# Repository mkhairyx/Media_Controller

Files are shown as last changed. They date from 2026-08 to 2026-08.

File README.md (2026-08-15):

# Gesture Based Media controller

## What is it
It's a device that controls your TV using IR signals to mimic your TV's remote control. It detects a gesture and then sends the signal that was coded for that gesture.

## The reason I made it
I made it so I can control different media without having to touch anything with my dirty hands while eating.

## Main modules used
- MCU: An ESP32
- Gesture Sensor: PAJ7620
- Display: OLED 0.96" SSD1306 Display

## Pins and their usages
- GPIO4: IR LED
- GPIO15: IR receiver (TL1838)
- GPIO21: SDA (for both the Gesture Sensor and the display)
- GPIO22: SCL (for both the Gesture Sensor and the display)
- GPIO18: delete button (Internally pulled high)

## How to recreate
You can either make the PCB with is [here](./source/pcbway_production/) or connect everything on a breadboard (while using [this](./README.md#pins-and-their-usages) as a reference) then you can flash the software provided [here](./Source/Arduino/Media_Controller_IRTXnRX) to your ESP32.

## Gestures and their functions
- Move Up / Move Down:<br>
Up Button / Down Button
- Move Left / Move Right:<br>
Left Button / Right Button
- Move Forward:<br>
OK button (for TV)
- Circle Clockwise (CW) / Circle Counter-Clockwise (CCW):<br>
Volume Up Button / Volume Down Button
- Wave (shake):<br>
switch between different TV/PC (Inoperative for now, PC functions will be available in V2)

## Demo Video
A demo vid can be watched here:<br>
https://youtu.be/PJmMg9s-Np0
https://cdn.hackclub.com/01a003da-1a12-7c9f-beef-b3fb1ff95faa/Media%20Controller%20Demo-2.mp4

## Notes
- Please note that AI was used to help with **some** parts of the code and not all of it.
- This is the first version of this project and it doesn't have all of the functions. V2 will have battery percentage measurement, better UI, and will be compatible with both TV and PC with the ability to switch between them.

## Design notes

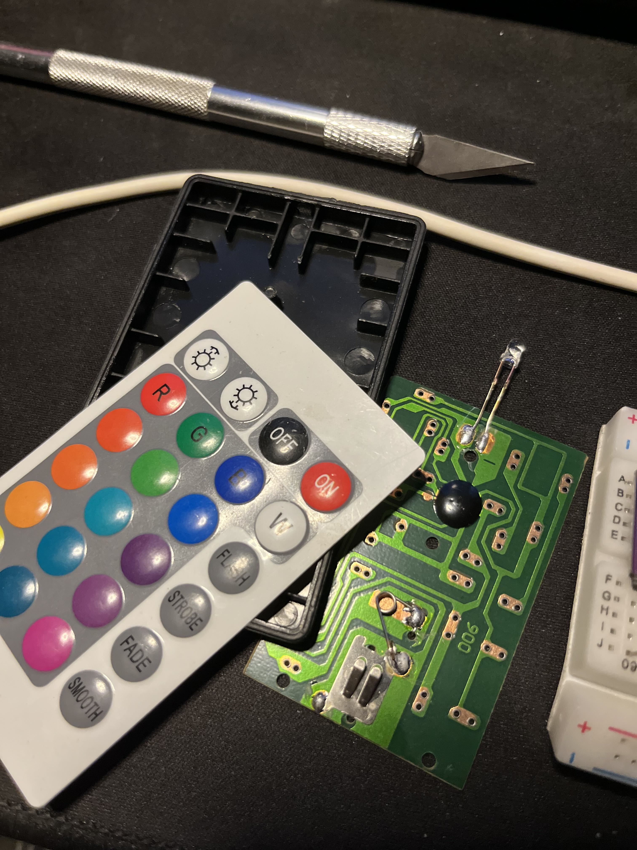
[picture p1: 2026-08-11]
Media/Camera/IR_Remote.jpg

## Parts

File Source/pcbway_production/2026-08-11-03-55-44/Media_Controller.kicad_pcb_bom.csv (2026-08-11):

Designator | Quantity | Value | Footprint | Package | MPN | DNP | Mount_Type | Description | KiLib_Generator | Sim.Pins | MF | Price | Check_prices | SnapEDA_Link | MP | Purchase-URL | Availability | MANUFACTURER | OC_FARNELL | SUPPLIER | OC_NEWARK
C1, C2, C3, C6 | 4 | 4.7uF | C_1206_3216Metric_Pad1.33x1.80mm_HandSolder |  |  |  | smt | Unpolarized capacitor | SMD_2terminal_chip_molded
C4 | 1 | 2.2uF | C_0805_2012Metric_Pad1.18x1.45mm_HandSolder |  |  |  | smt | Unpolarized capacitor | SMD_2terminal_chip_molded
C5, C7 | 2 | 100nF | C_1206_3216Metric_Pad1.33x1.80mm_HandSolder |  |  |  | smt | Unpolarized capacitor | SMD_2terminal_chip_molded
CHG1, PWR1 | 2 | SZYY0603Y | LED_0805_2012Metric_Pad1.15x1.40mm_HandSolder |  |  |  | smt | Light emitting diode | SMD_2terminal_chip_molded | 1=K 2=A
D1 | 1 | MBR120LSF | D_SMA_Handsoldering |  |  |  | smt | Schottky diode
D2 | 1 | IR | LED_D5.0mm |  |  |  | tht | Light emitting diode | LED/THT | 1=K 2=A
J1 | 1 | USB_C_Receptacle_USB2.0_16P | USB_C_Receptacle_GCT_USB4105-xx-A_16P_TopMnt_Horizontal |  |  |  | smt | USB 2.0-only 16P Type-C Receptacle connector
J2 | 1 | S2B-PH-SM4-TB | JST_EH_B2B-EH-A_1x02_P2.50mm_Vertical | None |  |  | tht | Connector Header Surface Mount, Right Angle 2 position 0.079 (2.00mm) | connector/JST |  | JST Sales | None | https://www.snapeda.com/parts/S2B-PH-SM4-TB/JST/view-part/?ref=eda | https://www.snapeda.com/parts/S2B-PH-SM4-TB/JST/view-part/?ref=snap | S2B-PH-SM4-TB | https://www.snapeda.com/api/url_track_click_mouser/?unipart_id=225866&manufacturer=JST Sales&part_name=S2B-PH-SM4-TB&search_term=s2b-ph-sm4-tb | In Stock | JST
J3 | 1 | polarity_ctrl | PinHeader_2x03_P2.54mm_Vertical |  |  |  | tht | Generic connector, double row, 02x03, odd/even pin numbering scheme (row 1 odd numbers, row 2 even numbers), script generated (kicad-library-utils/schlib/autogen/connector/) | connector/pin_header_socket
J4 | 1 | OLED | PinSocket_1x04_P2.54mm_Vertical |  |  |  | tht | Generic connector, single row, 01x04, script generated (kicad-library-utils/schlib/autogen/connector/) | connector/pin_header_socket
J5 | 1 | Gesture | PinSocket_1x05_P2.54mm_Vertical |  |  |  | tht | Generic connector, single row, 01x05, script generated | connector/pin_header_socket
Q3 | 1 | AO3401 | SOT-23 |  |  |  | smt | -0.18A Id, -60V Vds, P-Channel MOSFET, SOT-23 | package/gullwing
R1, R2 | 2 | 5.1k | R_Axial_DIN0207_L6.3mm_D2.5mm_P7.62mm_Horizontal |  |  |  | tht | Resistor | resistor/THT
R10 | 1 | 10k | R_0805_2012Metric_Pad1.20x1.40mm_HandSolder |  |  |  | smt | Resistor | SMD_2terminal_chip_molded
R11, R4, R5 | 3 | 2K | R_0805_2012Metric_Pad1.20x1.40mm_HandSolder |  |  |  | smt | Resistor | SMD_2terminal_chip_molded
R3, R6 | 2 | 10K | R_0805_2012Metric_Pad1.20x1.40mm_HandSolder |  |  |  | smt | Resistor | SMD_2terminal_chip_molded
R7 | 1 | 100 | R_0805_2012Metric_Pad1.20x1.40mm_HandSolder |  |  |  | smt | Resistor | SMD_2terminal_chip_molded
R8, R9 | 2 | 100K | R_0805_2012Metric_Pad1.20x1.40mm_HandSolder |  |  |  | smt | Resistor | SMD_2terminal_chip_molded
SW1 | 1 | Del | SW_PUSH_6mm_H13mm |  |  |  | tht | Push button switch, generic, two pins
SW3 | 1 | K3-1296S-E1_C128955 | SW_Slide_SPDT_Angled_CK_OS102011MA1Q |  |  |  | tht | Switch slide, single pole double throw
U1 | 1 | TSOP1838 | TSOP1838 | None |  |  | tht | IR Remote Receiver 38KHz 35m 3-Pin |  |  | Vishay | None | https://www.snapeda.com/parts/TSOP1838/Vishay/view-part/?ref=eda | https://www.snapeda.com/parts/TSOP1838/Vishay/view-part/?ref=snap | TSOP1838 | https://www.snapeda.com/api/url_track_click_mouser/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 | In Stock
U2 | 1 | MCP73831T-2ACI_OT | SOT-23-5_HandSoldering | SOT-5 | MCP73831T-2ACI/OT |  | smt | TINY INTEGRATED LI-ION/LI-POLY CHARGE MGNT CONTROLLER, 4.2V VREG | Microchip Technology Inc. MCP73831T-2ACI/OT |  |  | Microchip | None | https://www.snapeda.com/parts/MCP73831T-2ACI/OT/Microchip+Technology/view-part/?ref=eda | https://www.snapeda.com/parts/MCP73831T-2ACI/OT/Microchip+Technology/view-part/?ref=snap | MCP73831T-2ACI/OT | https://www.snapeda.com/api/url_track_click_mouser/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 | In Stock |  | 1332158 | Microchip | 56K7045
U4 | 1 | MIC5219-3.3YM5 | SOT-23-5_HandSoldering |  |  |  | smt | 500mA low dropout linear regulator, fixed 3.3V output, SOT-23-5
U6 | 1 | ~ | ESP32 DevKit |  |  |  | smt

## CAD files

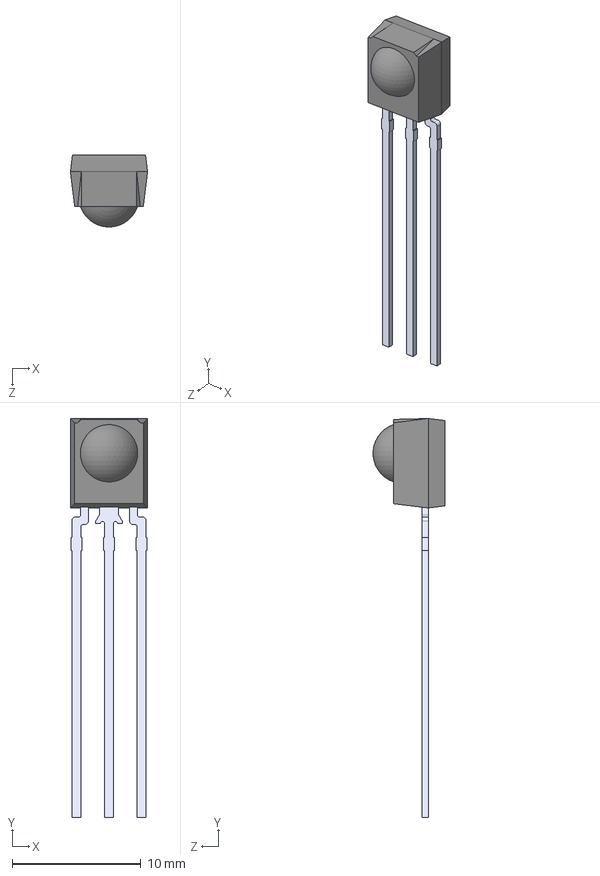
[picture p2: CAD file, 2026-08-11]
Source/KiCad/add-ons/TSOP1838/3D model/TSOP1838--3DModel-STEP-510211.STEP
6.00 x 31.0 x 5.59 mm

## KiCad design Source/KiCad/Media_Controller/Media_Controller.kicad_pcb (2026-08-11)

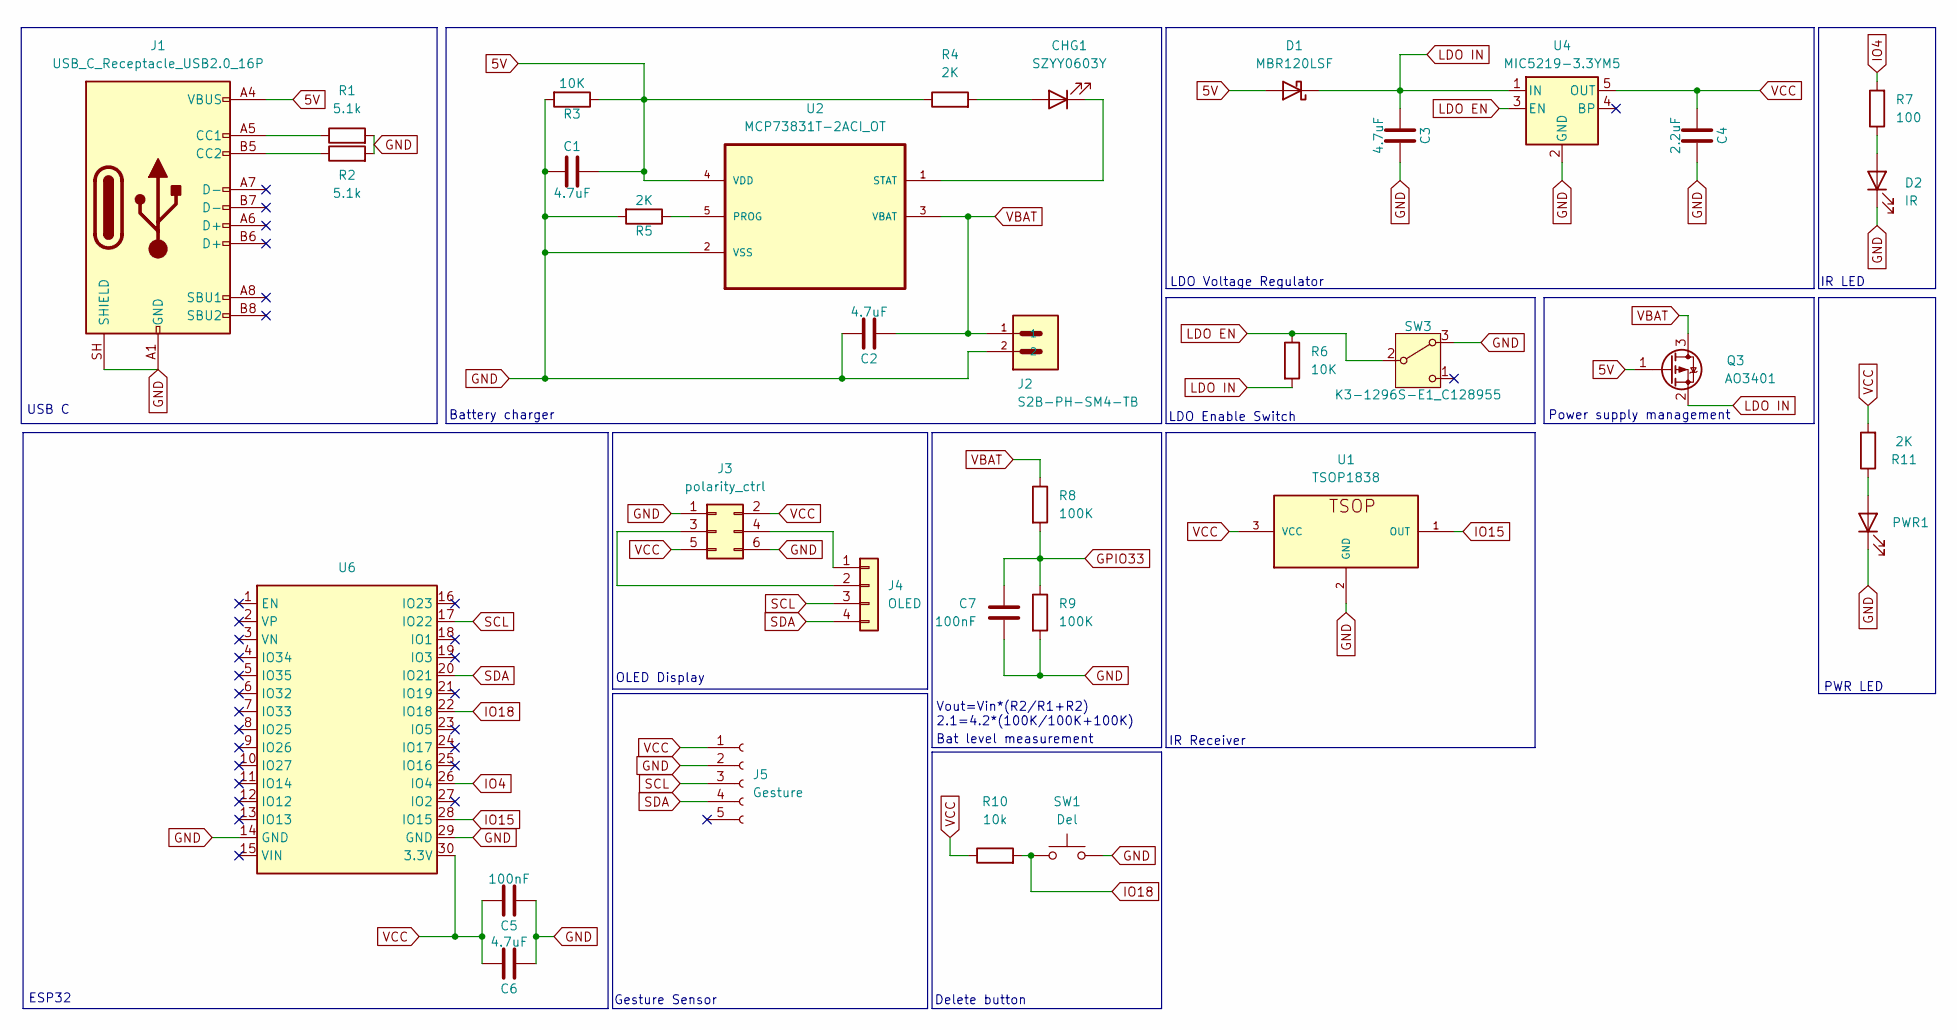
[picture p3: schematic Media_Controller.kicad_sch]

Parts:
C1, C2, C3, C6: 4.7uF; C_1206_3216Metric_Pad1.33x1.80mm_HandSolder
C4: 2.2uF; C_0805_2012Metric_Pad1.18x1.45mm_HandSolder
C5, C7: 100nF; C_1206_3216Metric_Pad1.33x1.80mm_HandSolder
CHG1: SZYY0603Y; LED_0805_2012Metric_Pad1.15x1.40mm_HandSolder
D1: MBR120LSF; D_SMA_Handsoldering
D2: IR; LED_D5.0mm
J1: USB_C_Receptacle_USB2.0_16P; USB_C_Receptacle_GCT_USB4105-xx-A_16P_TopMnt_Horizontal
J2: S2B-PH-SM4-TB; JST_EH_B2B-EH-A_1x02_P2.50mm_Vertical
J3: polarity_ctrl; PinHeader_2x03_P2.54mm_Vertical
J4: OLED; PinSocket_1x04_P2.54mm_Vertical
J5: Gesture; PinSocket_1x05_P2.54mm_Vertical
PWR1: SZYY0603Y; LED_0805_2012Metric_Pad1.15x1.40mm_HandSolder
Q3: AO3401; SOT-23
R1, R2: 5.1k; R_Axial_DIN0207_L6.3mm_D2.5mm_P7.62mm_Horizontal
R3, R6: 10K; R_0805_2012Metric_Pad1.20x1.40mm_HandSolder
R4, R5, R11: 2K; R_0805_2012Metric_Pad1.20x1.40mm_HandSolder
R7: 100; R_0805_2012Metric_Pad1.20x1.40mm_HandSolder
R8, R9: 100K; R_0805_2012Metric_Pad1.20x1.40mm_HandSolder
R10: 10k; R_0805_2012Metric_Pad1.20x1.40mm_HandSolder
SW1: Del; SW_PUSH_6mm_H13mm
SW3: K3-1296S-E1_C128955; SW_Slide_SPDT_Angled_CK_OS102011MA1Q
U1: TSOP1838
U2: MCP73831T-2ACI_OT; SOT-23-5_HandSoldering; MPN MCP73831T-2ACI/OT
U4: MIC5219-3.3YM5; SOT-23-5_HandSoldering
U6: ESP32 DevKit

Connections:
5V: C1.2, D1.2 (A), J1.A4 (VBUS), J1.A9 (VBUS), J1.B4 (VBUS), J1.B9 (VBUS), Q3.1 (G), R3.1, R4.1, U2.4 (VDD)
GND: C1.1, C2.2, C3.2, C4.2, C5.1, C6.1, C7.2, D2.1 (K), J1.A1 (GND), J1.A12 (GND), J1.B1 (GND), J1.B12 (GND), J1.SH (SHIELD), J2.2, J3.1, J3.6, J5.2, PWR1.1 (K), R1.2, R2.2, R3.2, R5.2, R9.2, SW1.2, SW3.3 (A), U1.2 (GND), U2.2 (VSS), U4.2 (GND), U6.14 (GND), U6.29 (GND)
GPIO33: C7.1, R8.2, R9.1
IO4: R7.2, U6.26 (IO4)
IO15: U1.1 (OUT), U6.28 (IO15)
IO18: R10.2, SW1.1, U6.22 (IO18)
LDO EN: R6.1, SW3.2 (B), U4.3 (EN)
LDO IN: C3.1, D1.1 (K), Q3.2 (S), R6.2, U4.1 (IN)
unnamed: CHG1.2 (A), R4.2
unnamed: CHG1.1 (K), U2.1 (STAT)
unnamed: D2.2 (A), R7.1
unnamed: J1.A5 (CC1), R1.1
unnamed: J1.B5 (CC2), R2.1
unnamed: J3.3, J4.2
unnamed: J3.4, J4.1
unnamed: PWR1.2 (A), R11.1
unnamed: R5.1, U2.5 (PROG)
SCL: J4.3, J5.3, U6.17 (IO22)
SDA: J4.4, J5.4, U6.20 (IO21)
VBAT: C2.1, J2.1, Q3.3 (D), R8.1, U2.3 (VBAT)
VCC: C4.1, C5.2, C6.2, J3.2, J3.5, J5.1, R10.1, R11.2, U1.3 (VCC), U4.5 (OUT), U6.30 (3.3V)

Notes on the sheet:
PWR LED
OLED Display
Delete button
LDO Enable Switch
Gesture Sensor
Power supply management
ESP32
IR Receiver
IR LED
Battery charger
Bat level measurement
USB C
Vout=Vin*(R2/R1+R2) 2.1=4.2*(100K/100K+100K)
LDO Voltage Regulator

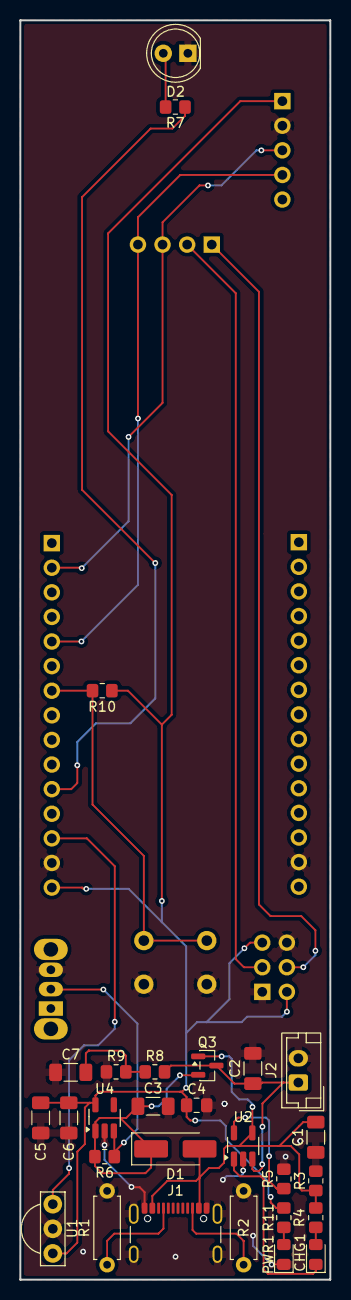
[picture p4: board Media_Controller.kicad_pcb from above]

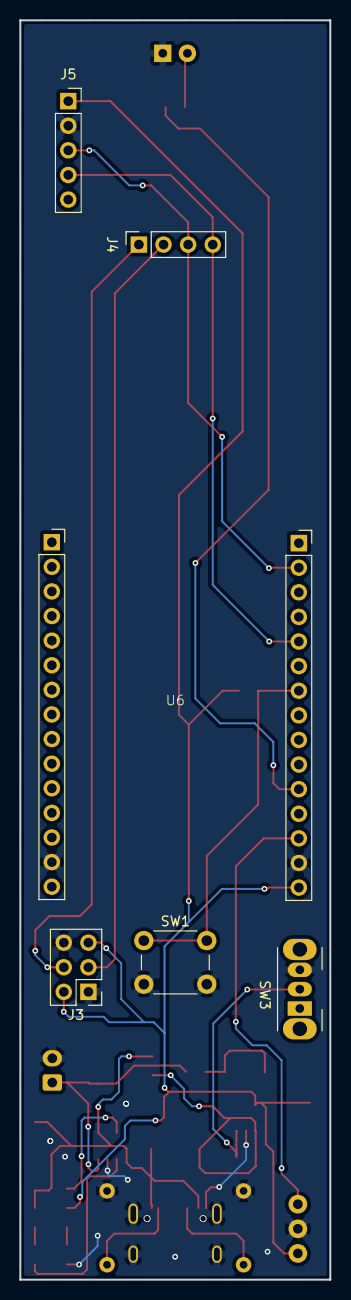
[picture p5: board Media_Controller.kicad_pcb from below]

Board: 2 copper layers, 32.0 x 130.0 mm, 34 parts (6 on the bottom side), 21 nets.

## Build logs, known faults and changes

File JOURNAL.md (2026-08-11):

---
title: "Gesture Based Media Controller"
author: "Mohamed Khairy"
description: "Touchless Gesture Based Media Controller that works with PC/TV"
created at: "2026-07-12"
---
### Total time spent: -- Hours

## Entry 1 - Getting started! - July 12th - 1.15 Hours

### Sketching out the design

At first I thought about making the device so it has a gesture sensor for media controls, and buttons for switching profiles (TV, PC, etc.).

Here's how I intended the design to look like:
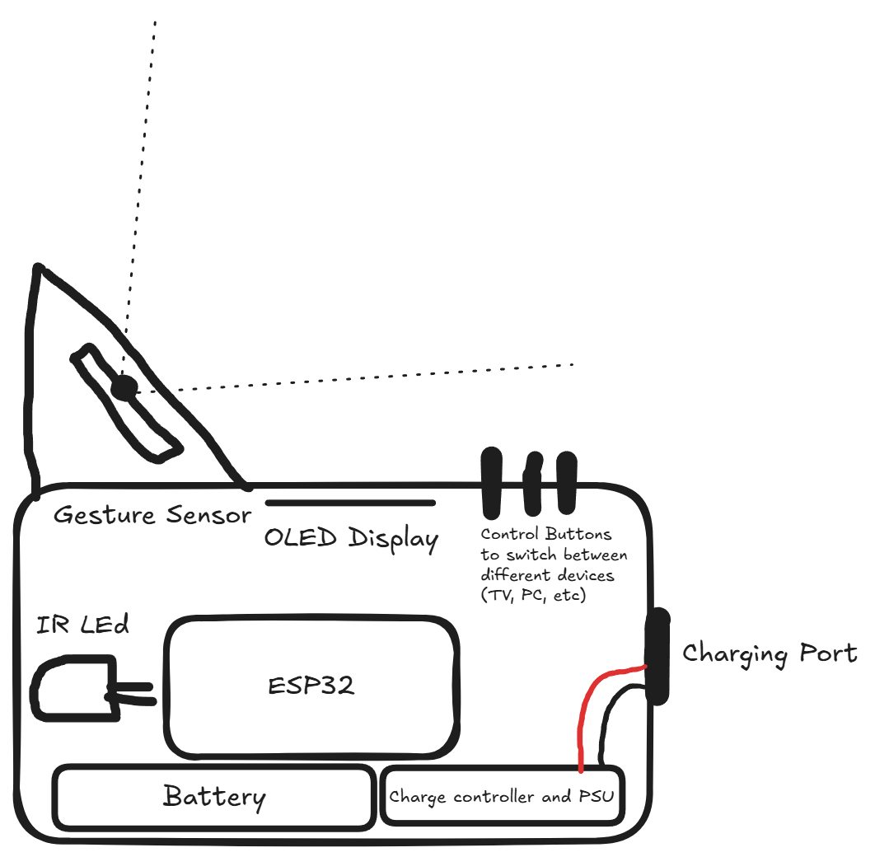
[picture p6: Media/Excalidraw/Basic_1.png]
Basic_1


But then I thought there's no need for the buttons, as I can use one of the gestures supported by the sensor to switch between TV/PC (using the Move Forward / Move Backward gestures). So I removed them and changed the design to not have them:
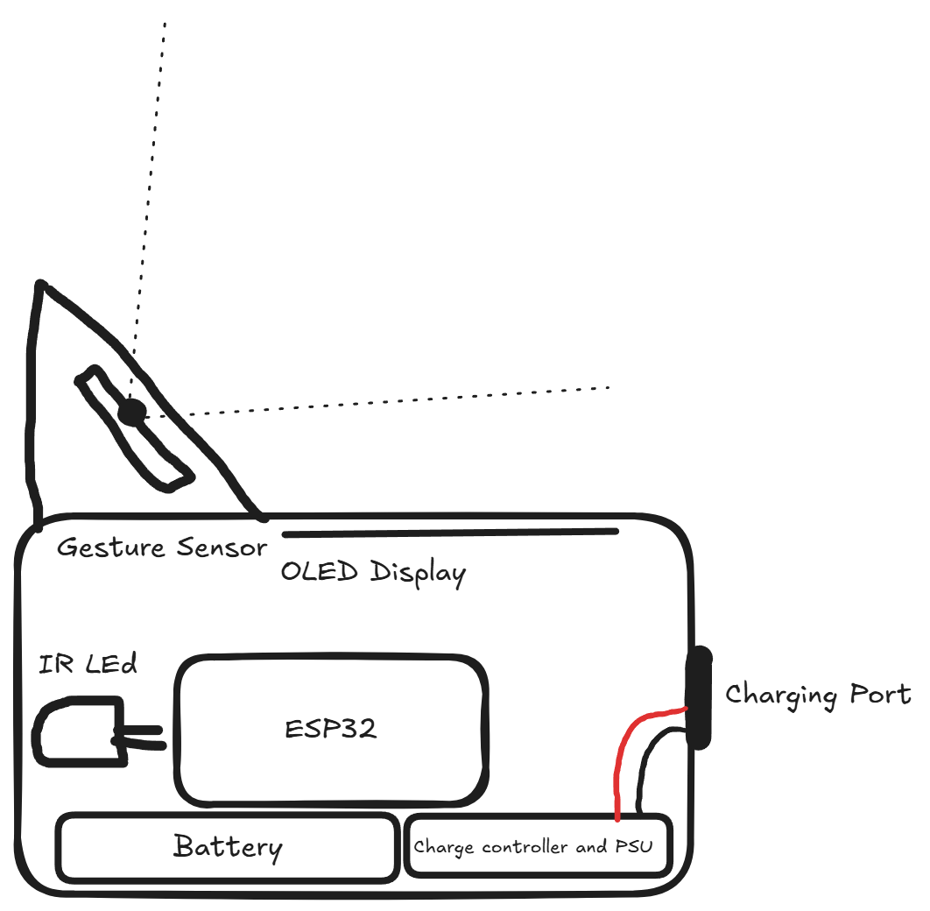
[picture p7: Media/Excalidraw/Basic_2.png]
Basic_2


Lapse recordings: <br>
[Media controller: Basic layout
](https://lapse.hackclub.com/timelapse/S1fzYW-wXMCX)<br>
[Finishing the 1st journal for media controller](https://lapse.hackclub.com/timelapse/r31FpIBMZaq-)<br>
***

## Entry 2 - Making a demo - August 8th - 2.05 Hours

### Putting the stuff on a breadboard

I Soldered some header pins to the gesture sensor and then I put everything on a breadboard.
I have the ESP32, the OLED display (which it's driver is a SSD1306) and the gesture sensor (A PAJ7620).<br>
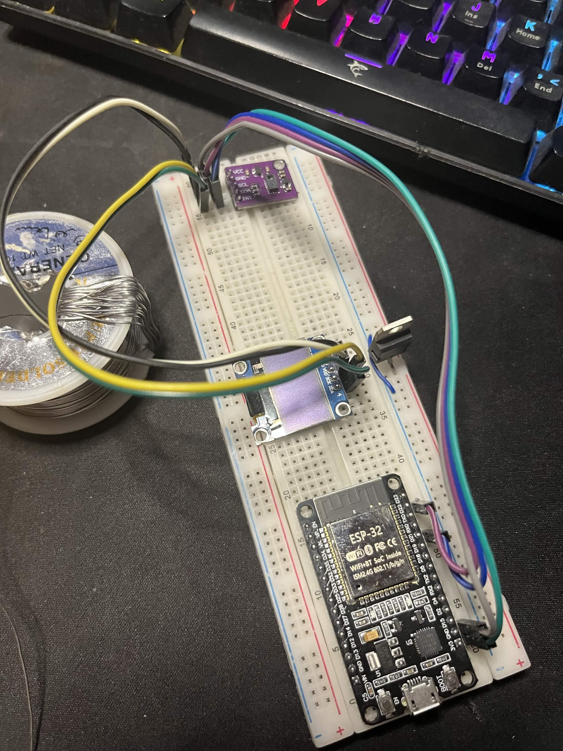
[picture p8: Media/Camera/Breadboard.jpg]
Breadboard
<br>

### Making a demo code

I ran a demo code for the sensor and everything worked great except one thing, the forward/backward gestures.<br>

After doing the forward gesture, you will have to pull your hand away, which triggers a false backward gesture.
Same thing with the backward gesture, you need to put your hand in front of the sensor then move away. Putting your hand in front of the sensor triggers a wrong gesture (wether be it a left, right, up, or down gesture).<br>

So I decided to disable the backward gesture and add a delay after the forward sensor so the user has time to pull away.<br>

After that, I ran some graphic tests from the U8g2 library to test the display. It worked great and I modified my code so it shows what gesture was recognized.

Then I added a rep counter so it shows how many times did you repeat the gesture.<br>

But after adding that, the ESP32 stopped recognizing gestures. So I decided to upload the original test code without my modifications to see if it will work or not, and it did work! <br>

Then I realized that the problem was with the rep counting function. Instead of changing the variable storing the last gesture, I was changing the variable storing the current gesture, which made it look like there is no gestures. I fixed it and it worked great!
<br>

Then I researched how to chain clockwise/counter-clockwise gestures. I gotta admit I used AI on this one, but I didn't fully rely on it. <br>
I spent some time fine tunning and testing the angles and gestures debouncing and it's working great!<br>

** a pic of the project with the screen displaying stuff **
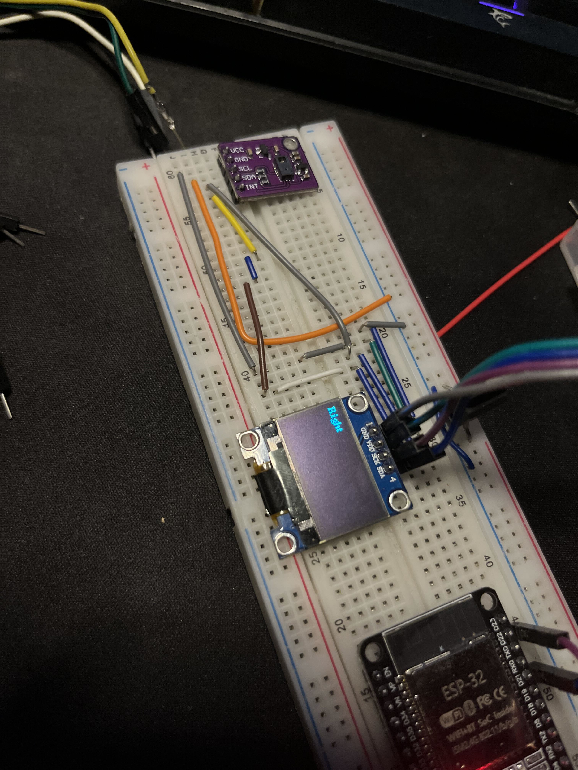
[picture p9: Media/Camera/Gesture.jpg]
Gesture


### What I'm doing next

Here's what I will be doing next:<br>
- get the ir sender and receiver ready
- make a test code that reads ir signals
- make a test code that sends hard coded ir signals
- make a test code that sends user coded ir signal (using an ir receiver)
- Make a code that pairs to a pc and controls media over bluetooth
- merge both functions together and let the user decided which function to use
- Make cool graphics for the display

<br>

Lapse recordings: <br>
[Making a code to interpret gestures](https://lapse.hackclub.com/timelapse/9EifI0f1eVn_)
 ***

## Entry 3 - Messing around with IR - August 8th - 0.9 Hours

### Getting the Breadboard ready

I put the IR receiver (TL1838 VS1838B) on the breadboard so I can mess around with it and figure out how the IR protocol works.

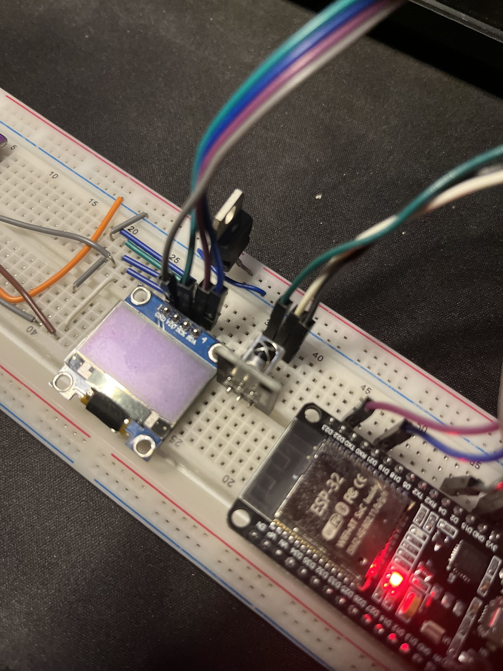
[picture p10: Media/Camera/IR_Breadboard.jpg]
IR_Breadboard


### Figuring out which protocol my TV uses

Using an oscilloscope, I discovered that my remote operates on NEC protocol which has a 1T of 562 µs.

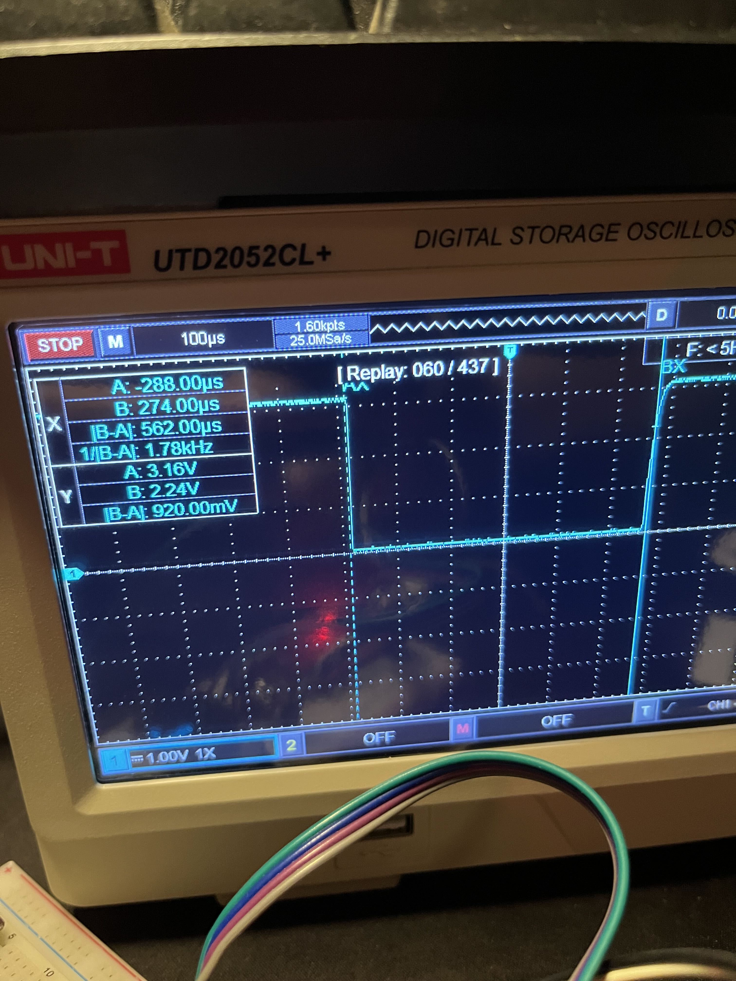
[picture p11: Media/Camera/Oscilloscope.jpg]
Oscilloscope


So I had claude make a code that reads IR signals and shows them to me on the serial monitor.<br>

It was getting late so  I decided that's enough for today.

### What I'm doing next

Here's what I will be doing next:<br>
- make a test code that sends hard coded ir signals
- make a test code that sends user coded ir signal (using an ir receiver)
- Make a code that pairs to a pc and controls media over bluetooth
- merge both functions together and let the user decided which function to use
- Make cool graphics for the display

<br>

Lapse recordings: <br>
[Testing IR receiver](https://lapse.hackclub.com/timelapse/zANNEGai21DX)
***

## Entry 4 - Sending signals with IR - August 9th - 1.3 Hours

### Getting an IR sender LED

I didn't have an IR LED so I decided to salvage one from my RGB LEDs controller.

** image of controller stripped apart **

### Making a test code for the IR led

I made a code for the IR LED to send hardcoded signals when some gestures are recognized but it didn't work. I accidentally burned the IR LED so I had to get another remote so I can salvage another LED and not burn it this time.

The code worked and the TV recognized the signals!

I spent some time trying to figure out how to store the IR data into the ESP32 non volatile storage. But I think I have done Enough for today.
<br>

Lapse recordings: <br>
[Getting the IR working](https://lapse.hackclub.com/timelapse/jJdBno_JCZZk)
***

## Entry 5 - Storing IR signals dynamically - August 10th - 2.2 Hours

Nothing much to say.
I made a code that utilizes the ESP32 NVS and stores the signals.<br>
I have also added a button that deletes the stored data (in case the user is having a new TV or anything similar).<br>

I was planning to make this device work with both TV and PC and I was going to make a better UI for it but I won't be able to do so as I'm extremely short on time. I'm satisfied with how it works for the moment.<br>

What's left is to make the schematic and the PCB for the device, then the enclosure.
<br>

Lapse recordings: <br>
[Storing IR signals dynamically](https://lapse.hackclub.com/timelapse/v13pgNrjCIoe)
***

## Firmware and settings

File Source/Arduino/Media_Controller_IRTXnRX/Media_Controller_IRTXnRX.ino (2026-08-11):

/////////////////////////////////////////////////////////////////////////////////
// This code does not have analog battery measurement for the moment.          //
// Analog battery mesurement will be added to the next version of this code.   //
//https://github.com/mkhairyx                                                  //
/////////////////////////////////////////////////////////////////////////////////

#include <Arduino.h>


// ESP32 NVS Headers
#include <Preferences.h>
Preferences TV;

// Display Library Headers
#include <U8g2lib.h>
U8G2_SSD1306_128X64_NONAME_F_HW_I2C u8g2(U8G2_R0, /* reset=*/ U8X8_PIN_NONE);
#ifdef U8X8_HAVE_HW_SPI
#include <SPI.h>
#endif
#ifdef U8X8_HAVE_HW_I2C
#include <Wire.h>
#endif

void u8g2_prepare(void) {
  u8g2.setFont(u8g2_font_6x10_tf);
  u8g2.setFontRefHeightExtendedText();
  u8g2.setDrawColor(1);
  u8g2.setFontPosTop();
  u8g2.setFontDirection(0);
}

bool del = 0;
volatile bool del_touch = 0;
#define delete_pin 18
void delete_function(void) {
  unsigned long trig = millis();
  
  u8g2.clearBuffer();					// clear the internal memory
  /*
  u8g2.setFont(u8g2_font_ncenB08_tr);	// choose a suitable font
  u8g2.drawStr(0,10,"Keep holding to delete");
  u8g2.drawStr(0,20,"stored data.");
  u8g2_prepare();
  u8g2.drawRFrame(2, 49,124,15, 5);
  u8g2.sendBuffer();
  */
  del = 0;
  while( (millis() - trig) < 5000 && del == 0)
  {
    u8g2.clearBuffer();					// clear the internal memory
    u8g2.setFont(u8g2_font_ncenB08_tr);	// choose a suitable font
    u8g2.drawStr(0,10,"Keep holding to delete");
    u8g2.drawStr(0,20,"stored data.");
    //u8g2_prepare();
    u8g2.drawRFrame(2, 49,124,15, 5);
    u8g2.sendBuffer();
    for (int i = 10; (i < 125) && !digitalRead(delete_pin); i++)
    {
      trig = millis();
      //u8g2.clearBuffer();
      //u8g2.drawRFrame(2, 49,124,15, 5);
      u8g2.drawRBox(2, 49,i,15, 5);
      u8g2.sendBuffer();
      delay(1);
      if (i == 124)
      {
        del = 1;
      }
    }
  }
  if (del == 1)
  {
    u8g2.clearBuffer();					// clear the internal memory
    u8g2.setFont(u8g2_font_ncenB08_tr);	// choose a suitable font
    u8g2.drawStr(0,10,"Deleting...");
    u8g2.sendBuffer();
    TV.begin("signals", false); 
    TV.clear();
    TV.end();
    delay(3500);
    u8g2.clearBuffer();					// clear the internal memory
    u8g2.setFont(u8g2_font_ncenB08_tr);	// choose a suitable font
    u8g2.drawStr(0,10,"Deleted!");
    u8g2.drawStr(0,20,"Restarting..");
    u8g2.sendBuffer();
    delay(1000);
    ESP.restart(); 
  }
  del_touch = 0;
  u8g2.clearBuffer();					// clear the internal memory
  u8g2.setFont(u8g2_font_ncenB08_tr);	// choose a suitable font
  u8g2.drawStr(0,10,"Waiting for gestures...");
  u8g2.sendBuffer();
}

void IRAM_ATTR delete_isr() 
{
  del_touch = 1;
}




// A structure for IRButton data type which stores name of the command, the command and the address.
struct IRButton {
  const char* name;
  uint8_t command;
  uint8_t address;
};

IRButton buttons[] =  {
    {.name = "left"},
    {.name = "right"},
    {.name = "up"},
    {.name = "down"},
    {.name = "ok"},
    {.name = "vol_up"},
    {.name = "vol_down"}
};


// IR Library Headers
/*
#if !defined(ARDUINO_ESP32C3_DEV) // This is due to a bug in RISC-V compiler, which requires unused function sections :-(.
#define DISABLE_CODE_FOR_RECEIVER // Disables static receiver code like receive timer ISR handler and static IRReceiver and irparams data. Saves 450 bytes program memory and 269 bytes RAM if receiving functions are not required.
#endif
//#define SEND_PWM_BY_TIMER         // Disable carrier PWM generation in software and use (restricted) hardware PWM.
//#define USE_NO_SEND_PWM           // Use no carrier PWM, just simulate an active low receiver signal. Overrides SEND_PWM_BY_TIMER definition
*/
#define NO_LED_FEEDBACK_CODE      // Saves 216 bytes program memory
#include "PinDefinitionsAndMore.h" // Define macros for input and output pin etc. Sets FLASHEND and RAMSIZE and evaluates value of SEND_PWM_BY_TIMER.
#include <IRremote.hpp>
/*
#define IR_RECEIVE_PIN 4
#define IR_SEND_PIN 18
*/

//struct Buttons




// Headers for the gesture sensor and math (for circular gestures)
// Includes enum definition of GES_* return values from readGesture()
#include "RevEng_PAJ7620.h"
#include <math.h>
// Create gesture sensor driver object
RevEng_PAJ7620 sensor = RevEng_PAJ7620();

// Variables to store last gesture and how many times it was repeated
Gesture last;
int reps = 1;

// Variables for the math that's used to recognize circular gestures
// ------------------------------------------------------------------
// Continuous clockwise/counter-clockwise volume control.
// Uses getObjectCenterX/Y (works in Gesture Mode, updates every loop,
// independent of readGesture()'s discrete GES_CLOCKWISE/ANTICLOCKWISE
// which only fires once the hand leaves view).
// ------------------------------------------------------------------
const float DEG_PER_STEP     = 120.0;  // degrees of rotation per volume step
const float DEADZONE_RADIUS  = 150.0; // ignore readings too close to the adaptive center
const float CENTER_EMA_ALPHA = 0.02;  // how fast the "center" adapts to hand drift
const int   VOLUME_STEP_SIZE = 1;     // volume change per applied step
// ------------------------------------------------------------------
// Debounce / activation thresholds for rotation steps
const int DEBOUNCE_STEPS      = 3; // consecutive same-direction steps before direction is "recognized"
const int VOLUME_START_STEPS  = 5; // consecutive same-direction steps before volume actually starts changing
// ------------------------------------------------------------------
int pendingDirection = 0; // 0 = none, +1 / -1 = current streak's direction
int pendingCount      = 0; // consecutive steps counted in pendingDirection
// ------------------------------------------------------------------
float lastAngle  = NAN;
float angleAccum = 0.0;
float centerX    = NAN;
float centerY    = NAN;
// ------------------------------------------------------------------
int volume = 50; // 0..100, replace with your actual volume interface

// *********************************************************************
void setup()
{
  Serial.begin(115200);

  pinMode(delete_pin, INPUT_PULLUP);
  attachInterrupt(digitalPinToInterrupt(delete_pin), delete_isr, FALLING);

  // u8g2 initialization
  u8g2.begin();
  u8g2.clearBuffer();					// clear the internal memory
  u8g2.setFont(u8g2_font_ncenB08_tr);	// choose a suitable font
  u8g2.drawStr(0,10,"System booted up!");
  u8g2.sendBuffer();					// transfer internal memory to the display
  Serial.println("Display initialized");
  delay(1000);

  // PAJ7620 initialization
  Serial.println("PAJ7620 sensor demo: Recognizing all 9 gestures.");
  if( !sensor.begin() )        // return value of 0 == success
  {
    Serial.print("PAJ7620 I2C error - halting");
    while(true) { }
  }
  Serial.println("PAJ7620 init: OK");
  Serial.println("Please input your gestures:");

  // IR initialization
  IrReceiver.begin(IR_RECEIVE_PIN, ENABLE_LED_FEEDBACK);
  Serial.println("IR Receiver ready");

  //NVS initialization (IR signals and codes)
  int stat; // storing that status of the namespace, 1 = exists, 0 = does not exist, 2 = error reading.
  TV.begin("signals", false);
  if (TV.isKey("signals")) // checking to see if a key was previously stored
  {
    // read the data
    size_t bytesRead = TV.getBytes("signals", &buttons, sizeof(buttons));
    if (bytesRead == sizeof(buttons))
    {
      Serial.println("Settings loaded successfully");
      stat = 1;
    }
    else
    {
      Serial.println("Error reading settings.");
      stat = 2;
    }
  } 
  else
  {
    // write the data
    stat = 0;
    u8g2.clearBuffer();
    u8g2.setFont(u8g2_font_ncenB08_tr);
    u8g2.drawStr(0,10,"No previously record-");
    u8g2.drawStr(0,20,"ed data found.");
    u8g2.sendBuffer();
    delay(1000);
    u8g2.clearBuffer();
    u8g2.setFont(u8g2_font_ncenB08_tr);
    u8g2.drawStr(0,10,"Learning new data...");
    u8g2.sendBuffer();
    delay(1000);
    for (int i = 0; i < 7; i++)  // go through seven gestures
    {
      u8g2.clearBuffer();
      u8g2.setFont(u8g2_font_ncenB08_tr);
      u8g2.drawStr(0,10,"Press the following-");
      u8g2.drawStr(0,20,"button:");
      u8g2.setCursor(40, 20);
      u8g2.print(buttons[i].name);
      u8g2.sendBuffer();

      while (!IrReceiver.decode())
      {
        delay(10);
      }

      int isnec = 0;
      while (isnec == 0)
      {
        if (IrReceiver.decode()) {
          if (IrReceiver.decodedIRData.protocol == NEC) {
              buttons[i].address = IrReceiver.decodedIRData.address; // already extracted, no manual bit math needed
              buttons[i].command = IrReceiver.decodedIRData.command;
              u8g2.clearBuffer();
              u8g2.setFont(u8g2_font_ncenB08_tr);
              u8g2.drawStr(0,10,"Signal recorded and ");
              u8g2.drawStr(0,20,"stored!");
              u8g2.sendBuffer();
              delay(1500);
              // store into your own buffer/struct here
              isnec = 1;
          } else {
              u8g2.drawStr(0,50,"Can't store this signal.");
              u8g2.drawStr(0,60,"Not NEC protocol!");
              u8g2.sendBuffer();
              isnec = 0;
          }
          IrReceiver.resume(); // ready for next signal
        }
      }
    }
    u8g2.clearBuffer();
    u8g2.setFont(u8g2_font_ncenB08_tr);
    u8g2.drawStr(0,10,"All signals recorded!");
    u8g2.drawStr(0,20,"Continuing..");
    u8g2.sendBuffer();
    delay(2000);

  }

  u8g2.clearBuffer();					// clear the internal memory
  u8g2.setFont(u8g2_font_ncenB08_tr);	// choose a suitable font
  u8g2.drawStr(0,10,"Waiting for gestures...");
  u8g2.sendBuffer();
  TV.putBytes("signals", &buttons, sizeof(buttons));
  TV.end();
}

// *********************************************************************
void loop()
{
  handleDiscreteGestures();
  handleRotationVolume();
  if (del_touch)
    delete_function();
  delay(10); // lowered from 100ms: rotation tracking needs finer polling
}

// *********************************************************************
void handleDiscreteGestures()
{
  Gesture gesture;                  // Gesture is an enum type from RevEng_PAJ7620.h
  gesture = sensor.readGesture();   // Read back current gesture (if any) of type Gesture

  // Make a counter for last gesture
  if (gesture == last)
  {
    reps++;
  }
  else if (gesture != GES_NONE)
  {
    reps = 1;
  }

  if(gesture != GES_NONE)
  {
    last = gesture;
  }

  switch (gesture)
  {
    case GES_FORWARD:
      {
        Serial.println("forward");
        u8g2.clearBuffer();
        u8g2.setFont(u8g2_font_ncenB08_tr);
        u8g2.drawStr(0,10,"Forward");
        u8g2.setCursor(0, 20);
        u8g2.print(reps);
        u8g2.sendBuffer();
        IrSender.sendNEC(buttons[4].address, buttons[4].command, 0); //ok button
        break;
      }

    case GES_BACKWARD:
      {
        break;
      }
    case GES_LEFT:
      {
        Serial.println("Left");
        u8g2.clearBuffer();
        u8g2.setFont(u8g2_font_ncenB08_tr);
        u8g2.drawStr(0,10,"Left");
        u8g2.setCursor(0, 20);
        u8g2.print(reps);
        u8g2.sendBuffer();
        IrSender.sendNEC(buttons[0].address, buttons[0].command, 0);
        break;
      }

    case GES_RIGHT:
      {
        Serial.println("Right");
        u8g2.clearBuffer();
        u8g2.setFont(u8g2_font_ncenB08_tr);
        u8g2.drawStr(0,10,"Right");
        u8g2.setCursor(0, 20);
        u8g2.print(reps);
        u8g2.sendBuffer();
        IrSender.sendNEC(buttons[1].address, buttons[1].command, 0);
        break;
      }

    case GES_UP:
      {
        Serial.println("Up");
        u8g2.clearBuffer();
        u8g2.setFont(u8g2_font_ncenB08_tr);
        u8g2.drawStr(0,10,"Up");
        u8g2.setCursor(0, 20);
        u8g2.print(reps);
        u8g2.sendBuffer();
        IrSender.sendNEC(buttons[2].address, buttons[2].command, 0);
        break;
      }

    case GES_DOWN:
      {
        Serial.println("Down");
        u8g2.clearBuffer();
        u8g2.setFont(u8g2_font_ncenB08_tr);
        u8g2.drawStr(0,10,"Down");
        u8g2.setCursor(0, 20);
        u8g2.print(reps);
        u8g2.sendBuffer();
        IrSender.sendNEC(buttons[3].address, buttons[3].command, 0);
        break;
      }

    // GES_CLOCKWISE / GES_ANTICLOCKWISE intentionally NOT handled here.
    // They only fire once, after the hand fully leaves the sensor's
    // view, so they can't drive continuous volume control. That's
    // handled separately in handleRotationVolume() below, using live
    // position tracking instead of the discrete gesture event.

    case GES_WAVE:
      {
        Serial.println("Wave");
        u8g2.clearBuffer();
        u8g2.setFont(u8g2_font_ncenB08_tr);
        u8g2.drawStr(0,10,"Wave");
        u8g2.setCursor(0, 20);
        u8g2.print(reps);
        u8g2.sendBuffer();
        // no tv command
        break;
      }

    default:
      {
        break;
      }
  }

  if(gesture == GES_FORWARD){
    delay(1500); // give the user enough time to pull away from the sensor
  }
}

// *********************************************************************
void handleRotationVolume()
{
  if (sensor.isObjectInView())
  {
    int x = sensor.getObjectCenterX();
    int y = sensor.getObjectCenterY();

    if (isnan(centerX))
    {
      // first valid reading after acquiring the object: seed the center
      centerX = x;
      centerY = y;
    }
    else
    {
      // slowly drift the center toward the current position, so it
      // settles near the middle of whatever circle is being traced.
      centerX += (x - centerX) * CENTER_EMA_ALPHA;
      centerY += (y - centerY) * CENTER_EMA_ALPHA;
    }

    float dx = x - centerX;
    float dy = y - centerY;
    float radius = sqrtf(dx * dx + dy * dy);

    if (radius > DEADZONE_RADIUS)
    {
      float angle = atan2f(dy, dx) * 180.0 / PI; // -180..180

      if (!isnan(lastAngle))
      {
        float delta = angle - lastAngle;

        // handle wraparound at +/-180
        if (delta > 180.0)  delta -= 360.0;
        if (delta < -180.0) delta += 360.0;

        angleAccum += delta;

        while (angleAccum >= DEG_PER_STEP)
        {
          angleAccum -= DEG_PER_STEP;
          processRotationStep(-1);
        }
        while (angleAccum <= -DEG_PER_STEP)
        {
          angleAccum += DEG_PER_STEP;
          processRotationStep(+1);
        }
      }
      lastAngle = angle;
    }
  }
  else
  {
    // hand left view: reset so we don't get a spurious jump on return
    lastAngle = NAN;
    angleAccum = 0.0;
    centerX = NAN;
    centerY = NAN;
    pendingDirection = 0;
    pendingCount = 0;
  }
}

// *********************************************************************
// Gate raw rotation steps through debounce + activation thresholds
// before letting them actually touch the volume.
void processRotationStep(int dir)
{
  if (dir == pendingDirection)
  {
    pendingCount++;
  }
  else
  {
    // direction changed (or first step ever): restart the streak
    pendingDirection = dir;
    pendingCount = 1;
  }

  if (pendingCount == DEBOUNCE_STEPS)
  {
    // direction just became "recognized" - optional feedback point
    Serial.println(dir > 0 ? "Direction recognized: Up" : "Direction recognized: Down");
  }

  if (pendingCount >= VOLUME_START_STEPS)
  {
    // streak is long enough: this step (and every one after it, as
    // long as direction keeps holding) actually changes the volume
    volumeStep(dir);
  }
}

// *********************************************************************
void volumeStep(int dir)
{
  volume = constrain(volume + dir * VOLUME_STEP_SIZE, 0, 100);
  Serial.print("Volume: ");
  Serial.println(volume);

  u8g2.clearBuffer();
  u8g2.setFont(u8g2_font_ncenB08_tr);
  u8g2.drawStr(0,10, dir > 0 ? "Volume Up" : "Volume Down");
  u8g2.setCursor(0, 20);
  u8g2.print(volume);
  u8g2.sendBuffer();
  if (dir == +1){
    IrSender.sendNEC(buttons[5].address, buttons[5].command, 0);
  }
  else if (dir == -1){
    IrSender.sendNEC(buttons[6].address, buttons[6].command, 0);
  }
}

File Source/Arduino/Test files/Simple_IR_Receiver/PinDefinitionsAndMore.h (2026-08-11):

/*
 *  PinDefinitionsAndMore.h
 *
 *  Contains pin definitions for IRremote examples for various platforms
 *  as well as definitions for feedback LED and tone() and includes
 *
 *  Copyright (C) 2021-2026  Armin Joachimsmeyer
 *  armin.joachimsmeyer@gmail.com
 *
 *  This file is part of IRremote https://github.com/Arduino-IRremote/Arduino-IRremote.
 *
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
 */

/*
 * Pin mapping table for different platforms
 *
 * Platform     IR input    IR output   Tone      Core/Pin schema
 * --------------------------------------------------------------
 * DEFAULT/AVR  2           3           4         Arduino
 * ATtinyX5     0|PB0       4|PB4       3|PB3     ATTinyCore
 * ATtiny167    3|PA3       2|PA2       7|PA7     ATTinyCore
 * ATtiny167    9|PA3       8|PA2       5|PA7     Digispark original core
 * ATtiny84      |PB2        |PA4        |PA3     ATTinyCore
 * ATtiny88     3|PD3       4|PD4       9|PB1     ATTinyCore
 * ATtiny3216  14|PA1      15|PA2      16|PA3     MegaTinyCore
 * ATtiny1604   2           3|PA5       %
 * ATtiny816   14|PA1      16|PA3       1|PA5     MegaTinyCore
 * ATtiny1614   8|PA1      10|PA3       1|PA5     MegaTinyCore
 * MKR*         1           3           4
 * SAMD         2           3           4
 * ESP8266      14|D5       12|D6       %
 * ESP32        4           15          27
 * ESP32-C3     2           3           4
 * ESP32-S3     2           3           4
 * BluePill     PA6         PA7       PA3
 * APOLLO3      11          12          5
 * RP2040       3|GPIO15    4|GPIO16    5|GPIO17
 */
//#define _IR_MEASURE_TIMING // For debugging purposes.

#if defined(__AVR__)
#if (defined(__AVR_ATtiny25__) || defined(__AVR_ATtiny45__) || defined(__AVR_ATtiny85__)) && defined(PIN_PB0) // Digispark board. For use with ATTinyCore.
#include "ATtinySerialOut.hpp" // TX is at pin 2 - Available as Arduino library "ATtinySerialOut". Saves 700 bytes program memory and 70 bytes RAM for ATtinyCore.
#define IR_RECEIVE_PIN  PIN_PB0
#define IR_SEND_PIN     PIN_PB4 // Pin 2 is serial output with ATtinySerialOut. Pin 1 is internal LED and Pin3 is USB+ with pullup on Digispark board.
#define TONE_PIN        PIN_PB3
#define _IR_TIMING_TEST_PIN PIN_PB3

#  elif defined(__AVR_ATtiny87__) || defined(__AVR_ATtiny167__) // Digispark pro board
#include "ATtinySerialOut.hpp" // Available as Arduino library "ATtinySerialOut"
// For ATtiny167 Pins PB6 and PA3 are usable as interrupt source.
#    if defined(ARDUINO_AVR_DIGISPARKPRO)
// For use with Digispark original core
#define IR_RECEIVE_PIN   9 // PA3 - on Digispark board labeled as pin 9
//#define IR_RECEIVE_PIN  14 // PB6 / INT0 is connected to USB+ on DigisparkPro boards
#define IR_SEND_PIN      8 // PA2 - on Digispark board labeled as pin 8
#define TONE_PIN         5 // PA7 - on Digispark board labeled as pin 5
#define _IR_TIMING_TEST_PIN 10 // PA4
#    elif  !defined(PIN_PA3)
#error ATtiny87 or ATtiny167 is not supported for the selected core. Please extend PinDefinitionsAndMore.h.
#    else
// For use with ATTinyCore
#define IR_RECEIVE_PIN  PIN_PA3 // On Digispark board labeled as pin 9 - INT0 is connected to USB+ on DigisparkPro boards
#define IR_SEND_PIN     PIN_PA2 // On Digispark board labeled as pin 8
#define TONE_PIN        PIN_PA7 // On Digispark board labeled as pin 5
#    endif

#  elif defined(__AVR_ATtiny84__) && defined(PIN_PB2) // For use with ATTinyCore
#include "ATtinySerialOut.hpp" // Available as Arduino library "ATtinySerialOut". Saves 128 bytes program memory.
#define IR_RECEIVE_PIN   PIN_PB2 // INT0
#define IR_SEND_PIN      PIN_PA4
#define TONE_PIN         PIN_PA3
#define _IR_TIMING_TEST_PIN PIN_PA5

#  elif defined(__AVR_ATtiny88__) && defined(PIN_PD3) // MH-ET Tiny88 board. For use with ATTinyCore.
#include "ATtinySerialOut.hpp" // Available as Arduino library "ATtinySerialOut". Saves 128 bytes program memory.
// Pin 6 is TX, pin 7 is RX
#define IR_RECEIVE_PIN   PIN_PD3 // 3 - INT1
#define IR_SEND_PIN      PIN_PD4 // 4
#define TONE_PIN         PIN_PB1 // 9
#define _IR_TIMING_TEST_PIN PIN_PB0 // 8

#  elif (defined(__AVR_ATtiny1616__) || defined(__AVR_ATtiny3216__) || defined(__AVR_ATtiny3217__)) && defined(PIN_PA1) // For use with megaTinyCore
// Tiny Core Dev board
// https://www.tindie.com/products/xkimi/tiny-core-16-dev-board-attiny1616/ - Out of Stock
// https://www.tindie.com/products/xkimi/tiny-core-32-dev-board-attiny3217/ - Out of Stock
#define IR_RECEIVE_PIN   PIN_PA1 // 14 use 18 instead of PIN_PA1 for TinyCore32
#define IR_SEND_PIN      PIN_PA2 // 15, 19 for TinyCore32
#define TONE_PIN         PIN_PA3 // 16, 20 for TinyCore32
#define APPLICATION_PIN  PIN_PC3 // 13, PIN_PA0 is RESET
#undef LED_BUILTIN               // No LED available on the TinyCore 32 board, take the one on the programming board which is connected to the DAC output
#define LED_BUILTIN      PIN_PA6 // use 2 instead of PIN_PA6 for TinyCore32
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

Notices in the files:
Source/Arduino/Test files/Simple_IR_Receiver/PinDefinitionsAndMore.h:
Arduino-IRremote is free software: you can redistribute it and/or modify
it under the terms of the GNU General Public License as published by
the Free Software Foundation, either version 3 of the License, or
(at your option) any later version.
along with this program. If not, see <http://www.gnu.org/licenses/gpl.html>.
